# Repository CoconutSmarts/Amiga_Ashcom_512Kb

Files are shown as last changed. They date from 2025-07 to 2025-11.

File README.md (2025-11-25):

# Amiga_Ashcom_512Kb
Reproduction of the PCB for an Ashcom 512kb memory expansion, for Amiga 500s.   This was done as a learning exercise, after finding an Ashcom board with battery damage.  Rather than bodge the damaged board, I decided to replace the board.  Of course it would have been quicker and cheaper to buy a more modern equivalent, but where's the fun in that?

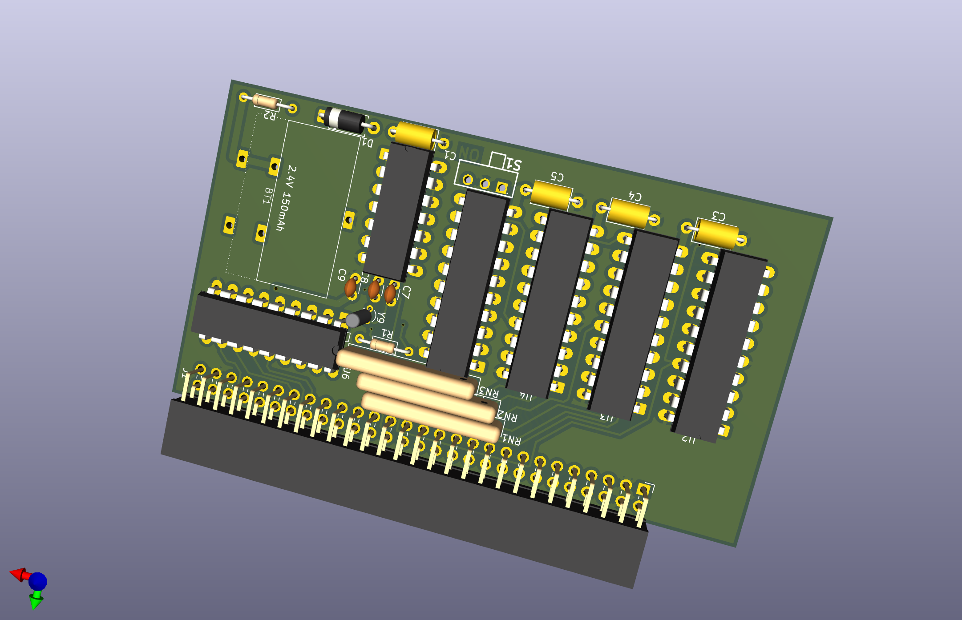
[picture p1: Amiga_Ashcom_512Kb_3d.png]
3D Model


## Reproduction
The KiCad files (schematic and pcb) are available here.   Note the schematic and pcb were drawn separately.  I started with the intention of just re-creating the PCB, but then decided to create the schematic for completeness.  If there are any design issues with the expansion, then the issues will persist in this reproduction.  Along the same lines, neither I have replaced the battery with a CR2032.

## KiCAD Version 
KiCAD version 9.0.3.   The schematic and PCB are contained in the schematic.   The schematic was reversed manually from the PCB, so could contain errors.   The PCB should be considered the golden source.

## Oddities
The dsign seems a somewhat more basic (and cheaper) design that the official A501 expansion.  Perhaps related to this, a few curiousities were found:-
1) Pin 5 of the memory chips are documented as Not Connected.   Yet the PCB connects these pins to GND.
2) Pin 34 and Pin 33 on the connector are shorted.   Using Raemixx500 as a reference, these pins seem to be ~CLKCS and GND.  On an Amiga 501 the signal is sent to the RTC ~CS0 input, on the Ashcom it is grounded.  Another cost saving decision?
3) The RTC clock circuit has no variable capacitor (the A501 has a fixed and variable capacitor with the crystal).
4) The holes for C9 are present on the original PCB, but not populated.  As there are no component markings, Ive assumed this was intended for a capacitor across VDD and GND (on the RTC IC), but the manufacturer obviously didnt feel this capacitor was necessary.
5) There are no decoupling capacitors across VCC and GND for U2 and U6.  Either the manufacturer didn't think decoupling capacitors were needed for U2 and U5, or it's another cost saving decision.

In summary this seems a stripped down design when compared to the A501.  Does this have any nagative implications?

## Gerbers and PCB Production
Gerber files were successfully produced by PCBWAY.   After building the board was tested in an Amiga 500 (1.3 workbench) with no issues.

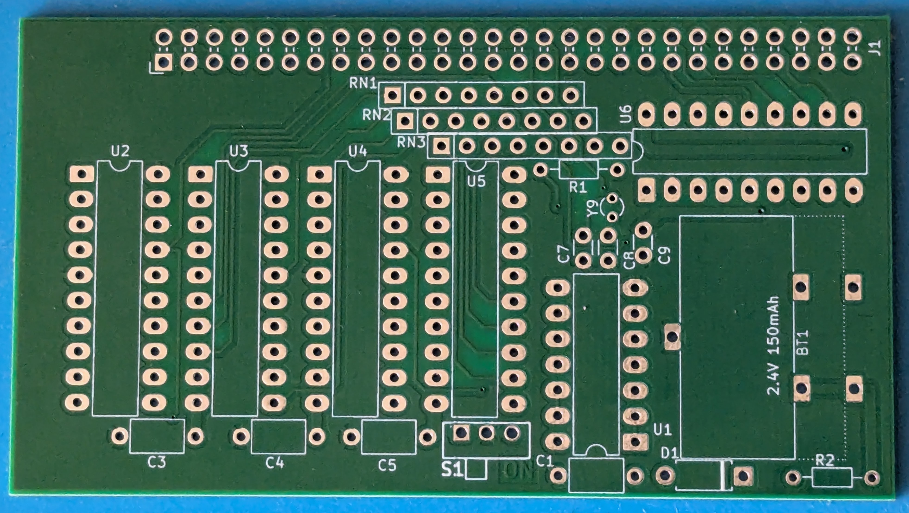
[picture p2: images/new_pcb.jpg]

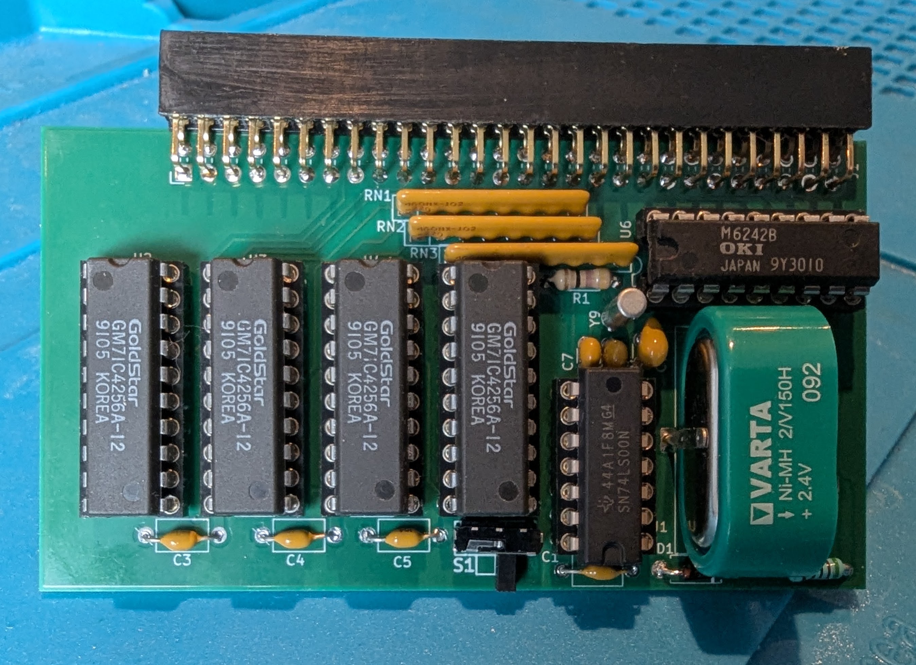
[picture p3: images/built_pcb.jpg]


Using Amiga Test Kit, the memory and RTC tested successfully:-

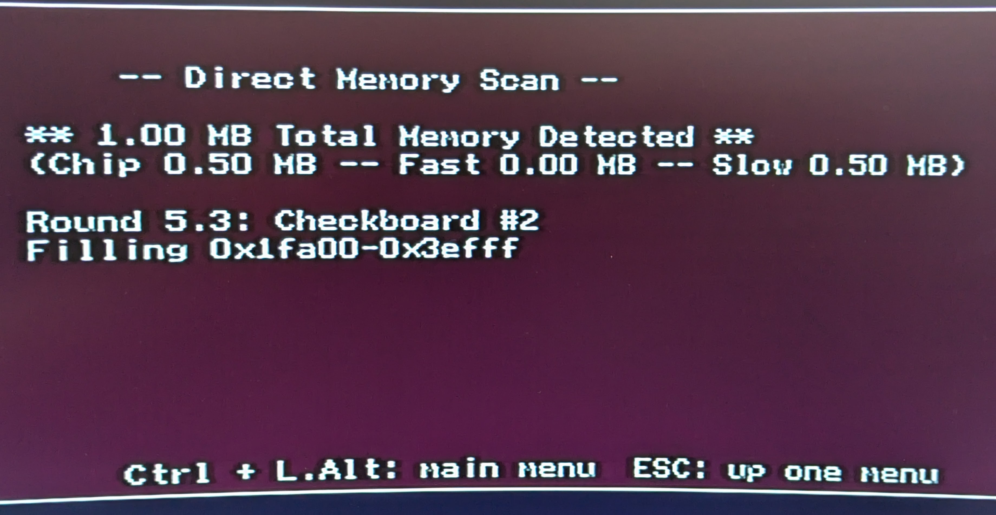
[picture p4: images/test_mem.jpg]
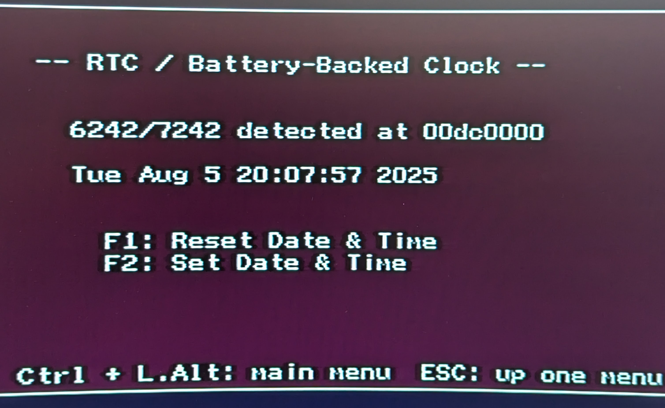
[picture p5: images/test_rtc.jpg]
 -  

## BOM

| Id | Designator | Footprint | Quantity | Designation Supplier | ref |
| --- | --- | --- | --- | --- | --- |
|1|C7,C8|C_Disc_D3.0mm_W1.6mm_P2.50mm|2|22pF|
|2|BT1|Varta_2.4v_150mAh|1|2.4V 150mAh|
|3|Y9|Crystal_C26-LF_D2.1mm_L6.5mm_Vertical|1|32768Hz|
|4|C1,C3,C4,C5,C9|C_Axial_L5.1mm_D3.1mm_P7.50mm_Horizontal|5|100nF|
|5|RN1,RN3,RN2|R_Array_SIP8|3|22ohm|
|6|D1|D_A-405_P7.62mm_Horizontal|1|1N914|			
|7|U1|DIP-14_W7.62mm_LongPads|1|74LS00N|	
|8|S1|780565|1|SPDT Switch, Right Angle, 2.54mm pitch, Enable/Disable|
|9|U2,U3,U4,U5|DIP-20_W7.62mm_LongPads|4|DRAM 256Kx4-bit DIP20|
|10|J1|PinSocket_2x28_P2.54mm_Horizontal|1|Female trap door connector 2x28 2.54mm Right Angled|
|11|U6|DIP-18_W7.62mm_LongPads|1|M6242B RTC|
|12|R1|R_Axial_DIN0204_L3.6mm_D1.6mm_P7.62mm_Horizontal|1|47ohm|
|13|R2|R_Axial_DIN0204_L3.6mm_D1.6mm_P7.62mm_Horizontal|1|510ohm|

The PCB seems designed for a 2.4V or a 3.6V NiMh rechargeable battery.  R2 is sized to trickle charge a 2.4v cell at around 4mA.   R2 should be changed accordingly if a 3.6v cell is used.  By my calcs that would be around 200ohms, but I have not tested this configuration.

The RTC components can be left out, and the board will then just function as a memory expansion (C7, C8, C9, Y9, BT1, D1, R2, U6, C9 can be omitted).

## References
1) https://github.com/SukkoPera/Raemixx500 
2) https://amigawiki.org/dnl/schematics/A500_R6.pdf

## Damaged PCB Pictures
The following pictures show the original PCBs, and were used to recreate the PCB layout.
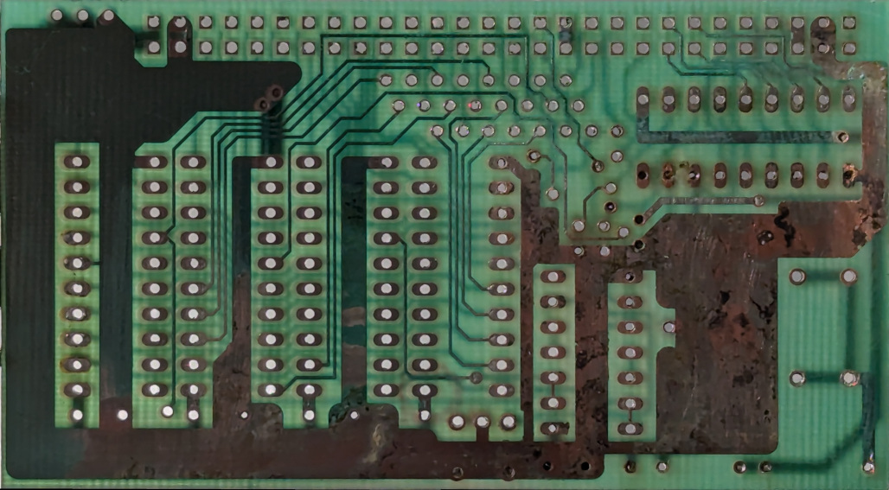
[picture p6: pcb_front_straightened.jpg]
PCB Front Image

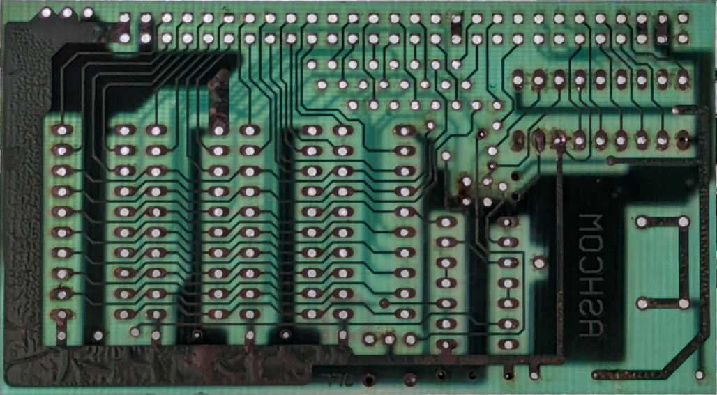
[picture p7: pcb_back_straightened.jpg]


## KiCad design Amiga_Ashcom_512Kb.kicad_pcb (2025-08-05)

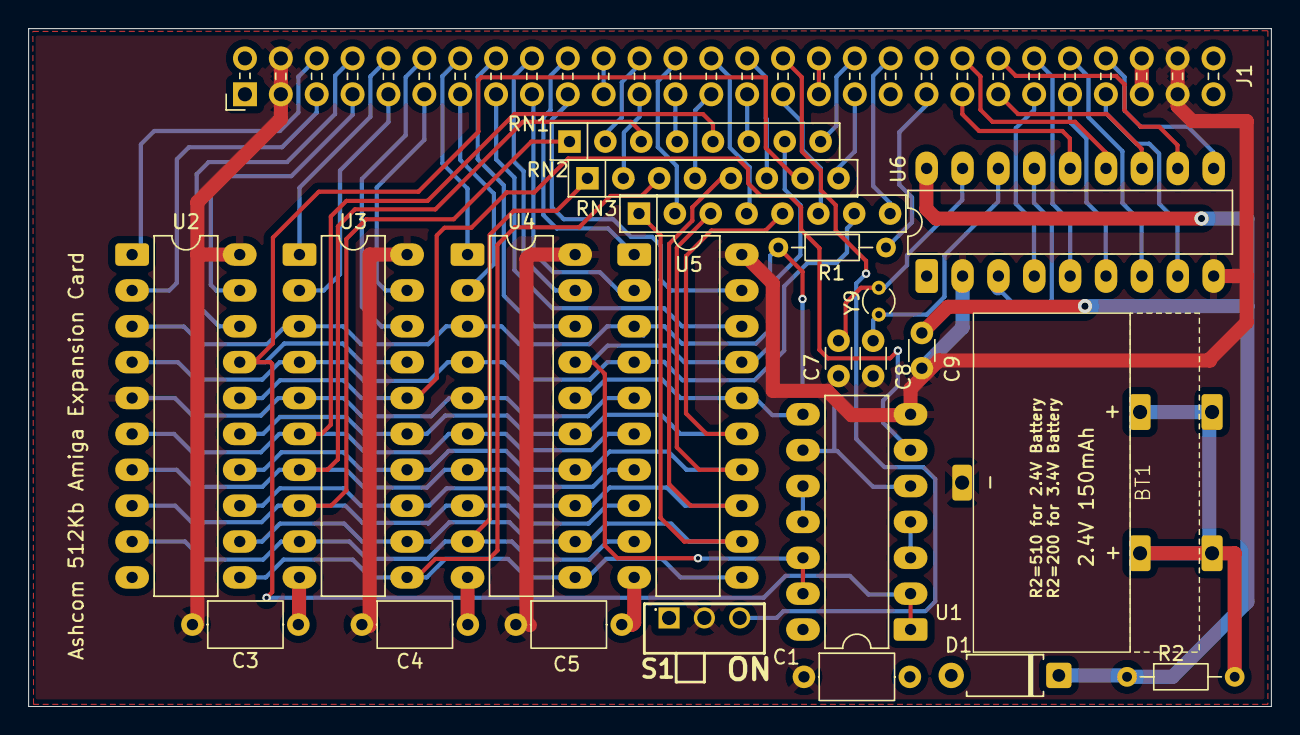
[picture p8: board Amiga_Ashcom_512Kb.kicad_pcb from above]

Board: 2 copper layers, 88.0 x 48.0 mm, 23 parts (0 on the bottom side), 65 nets.

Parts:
BT1: 2.4V 150mAh; Varta_2.4v_150mAh
C1, C3, C4, C5: 100nF; C_Axial_L5.1mm_D3.1mm_P7.50mm_Horizontal
C7, C8: 22pF; C_Disc_D3.0mm_W1.6mm_P2.50mm
C9: 100nF; C_Disc_D3.0mm_W1.6mm_P2.50mm
D1: 1N914; D_A-405_P7.62mm_Horizontal
J1: PinSocket_2x28_P2.54mm_Horizontal
R1: 47; R_Axial_DIN0204_L3.6mm_D1.6mm_P7.62mm_Horizontal
R2: 510; R_Axial_DIN0204_L3.6mm_D1.6mm_P7.62mm_Horizontal
RN1, RN2, RN3: 22; R_Array_SIP8
S1: Enable/Disable; 780565
U1: 74LS00N; DIP-14_W7.62mm_LongPads
U2, U3, U4, U5: 256kb x 4; DIP-20_W7.62mm_LongPads
U6: M6242B; DIP-18_W7.62mm_LongPads
Y9: 32768Hz; Crystal_C26-LF_D2.1mm_L6.5mm_Vertical

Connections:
+2.4V: BT1.2, BT1.3, R2.2
A0: RN2.1, U2.9, U3.9, U4.9, U5.9
A1: RN1.1, U2.8, U3.8, U4.8, U5.8
A2: RN1.3, U2.7, U3.7, U4.7, U5.7
A3: RN3.1, U2.12, U3.12, U4.12, U5.12
A4: RN2.3, U2.11, U3.11, U4.11, U5.11
A5: RN3.3, U2.14, U3.14, U4.14, U5.14
A6: RN1.5, U2.6, U3.6, U4.6, U5.6
A7: RN2.5, U2.13, U3.13, U4.13, U5.13
A8: RN3.5, U2.15, U3.15, U4.15, U5.15
BDRA0: J1.23, RN2.2
BDRA1: J1.24, RN1.2
BDRA2: J1.25, RN1.4
BDRA3: J1.26, RN3.2
BDRA4: J1.27, RN2.4
BDRA5: J1.28, RN3.4
BDRA6: J1.29, RN1.6
BDRA7: J1.30, RN2.6
BDRA8: J1.31, RN3.6
CASL: U1.3, U1.4
CASU: U1.10, U1.11
DRD0: J1.5, U2.2
DRD1: J1.6, U2.1
DRD2: J1.7, U2.19
DRD3: J1.8, U2.18
DRD4: J1.9, U3.2
DRD5: J1.10, U3.1
DRD6: J1.11, U3.19
DRD7: J1.12, U3.18
DRD8: J1.13, U4.2
DRD9: J1.14, U4.1
DRD10: J1.15, U5.18
DRD11: J1.16, U4.18
DRD12: J1.17, U5.2
DRD13: J1.18, U4.19
DRD14: J1.19, U5.19
DRD15: J1.20, U5.1
GND: BT1.1, C1.1, C3.1, C4.1, C5.1, C7.2, C8.2, C9.2, J1.3, J1.4, J1.53, J1.54, S1.2, U1.7, U2.5, U2.20, U3.5, U3.20, U4.5, U4.20, U5.5, U5.20, U6.2, U6.9
Link_21_22: J1.21, J1.22
Link_33_34: J1.33, J1.34
VCC: C1.2, C3.2, C4.2, C5.2, D1.2, J1.1, J1.2, J1.51, J1.52, U1.14, U2.10, U3.10, U4.10, U5.10, U6.3, U6.15
VDD: C9.1, D1.1, R2.1, U6.18
XA2: J1.45, U6.4
XA3: J1.46, U6.5
XA4: J1.47, U6.6
XA5: J1.48, U6.7
XD0: J1.41, U6.14
XD1: J1.42, U6.13
XD2: J1.43, U6.12
XD3: J1.44, U6.11
XT: C8.1, U6.16, Y9.2
~BCASL1: J1.35, RN2.8
~BCASU1: J1.36, RN1.8
~BRAS0: J1.38, RN3.8
~BWE: J1.39, R1.2
~CASL: RN2.7, U1.1, U1.2, U2.17, U3.17
~CASU: RN1.7, U1.12, U1.13, U4.17, U5.17
~CLKRD: J1.49, U6.8
~CLKWR: J1.50, U6.10
~EXRAM: J1.32, S1.3
~OEL: U1.6, U2.16, U3.16
~OEU: U1.8, U4.16, U5.16
~RAS: RN3.7, U2.4, U3.4, U4.4, U5.4
~WE: R1.1, U1.5, U1.9, U2.3, U3.3, U4.3, U5.3
~XT: C7.1, U6.17, Y9.1

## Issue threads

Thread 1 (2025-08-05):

PCB is slightly too thin (add 0.5mm to both sides)

CoconutSmarts, 2025-08-05:
Board fits perfectly in the amiga trap door, but there is a little too much wiggle room.

Update the PCB to be 0.5mm wider on each side.

CoconutSmarts, 2025-08-05:
Width extended by 0.25mm and 0.75mm (rather than 0.5 on each side).

Closed 2025-08-05.

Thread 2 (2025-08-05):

The ON / OFF screen print is barely visible as it is not on the silk screen layer

CoconutSmarts, 2025-08-05:
Move the ON/OFF text to the silk screen layer

CoconutSmarts, 2025-08-05:
PCB updated.   ON/OFF moved to the silkscreen, plus additional info added to the silkscreen.

Closed 2025-08-05.

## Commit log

2025-07-23 Initial version of PCB and Schematic
    [Amiga_Ashcom_512Kb.kicad_pcb, Amiga_Ashcom_512Kb.kicad_sch]
2025-07-24 Annotated the schematic to match the PCB, and added experimental gerbers.
    [Amiga_Ashcom_512Kb.kicad_pcb, Amiga_Ashcom_512Kb.kicad_sch]
2025-08-01 Update README.md, add BOM
2025-08-02 Fix R1/R2 references and values, change C9 to 100nF
    [Amiga_Ashcom_512Kb.kicad_pcb, Amiga_Ashcom_512Kb.kicad_sch]
2025-08-05 Slightly increase width of board, move ON/OFF to correct layer, add additional info to silkscreen.
    [Amiga_Ashcom_512Kb.kicad_pcb]
2025-08-05 Add new version of gerbers.
